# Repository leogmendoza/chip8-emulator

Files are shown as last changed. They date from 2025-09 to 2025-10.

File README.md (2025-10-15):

# 🍪 CHIP ATE
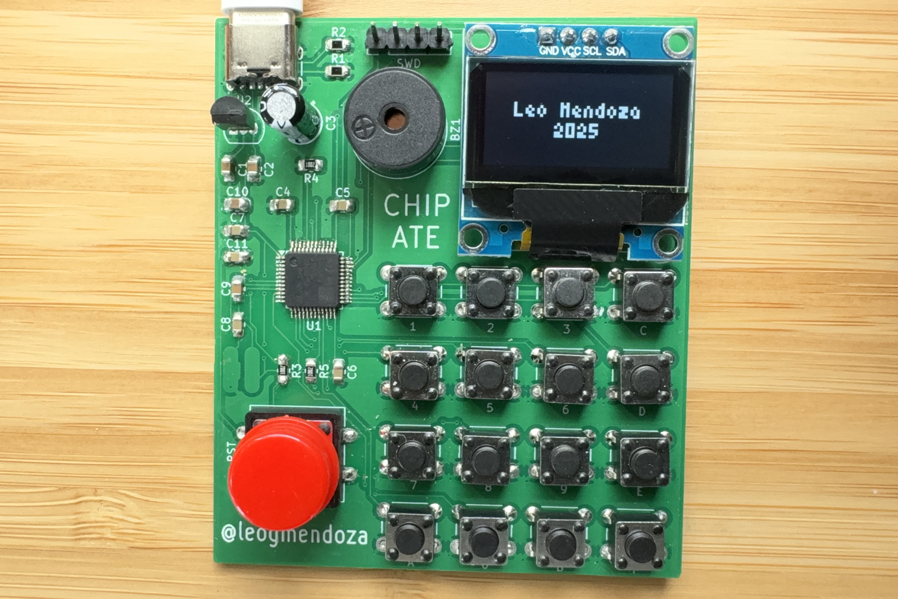
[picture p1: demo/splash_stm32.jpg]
 

## 🤔 What?
CHIP ATE is a CHIP-8 Emulator implemented on both PC using SDL2 and STM32 with a custom PCB!

## 🤨 Why?
This was supposed to be my first step into console emulation, but then it became that for PCB design as well!

## Features
- **Portable Emulator Core**:  
  Implements the timers, memory, and CPU as per the [official CHIP-8 spec](http://devernay.free.fr/hacks/chip8/C8TECH10.HTM), including all 34 instructions

- **Platform Abstraction Layer**:  
  Able to run on either PC or STM32 using a platform-agnostic API layer
  
- **Custom PCB**:  
  Assembled on a STM32-based board with an OLED screen, keypad, a buzzer, and power regulation
  
- **ROM Menu**:  
  Provides seamless loading in and out of the ROM catalog

## Diagrams

### System Architecture
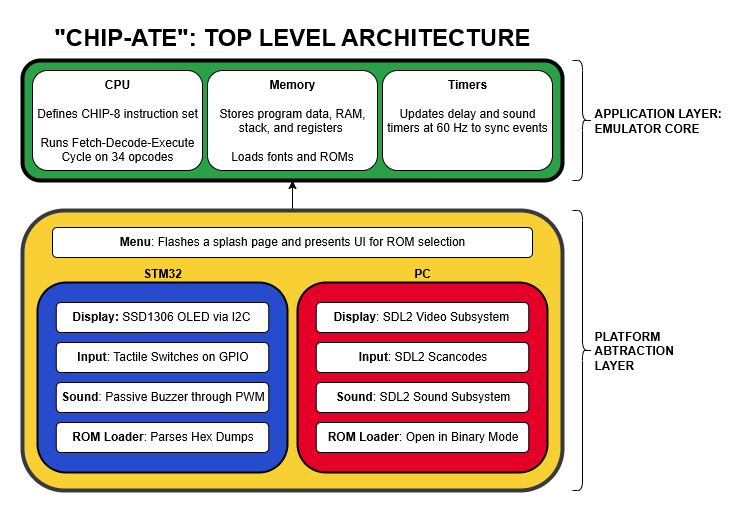
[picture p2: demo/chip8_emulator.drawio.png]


### Schematic
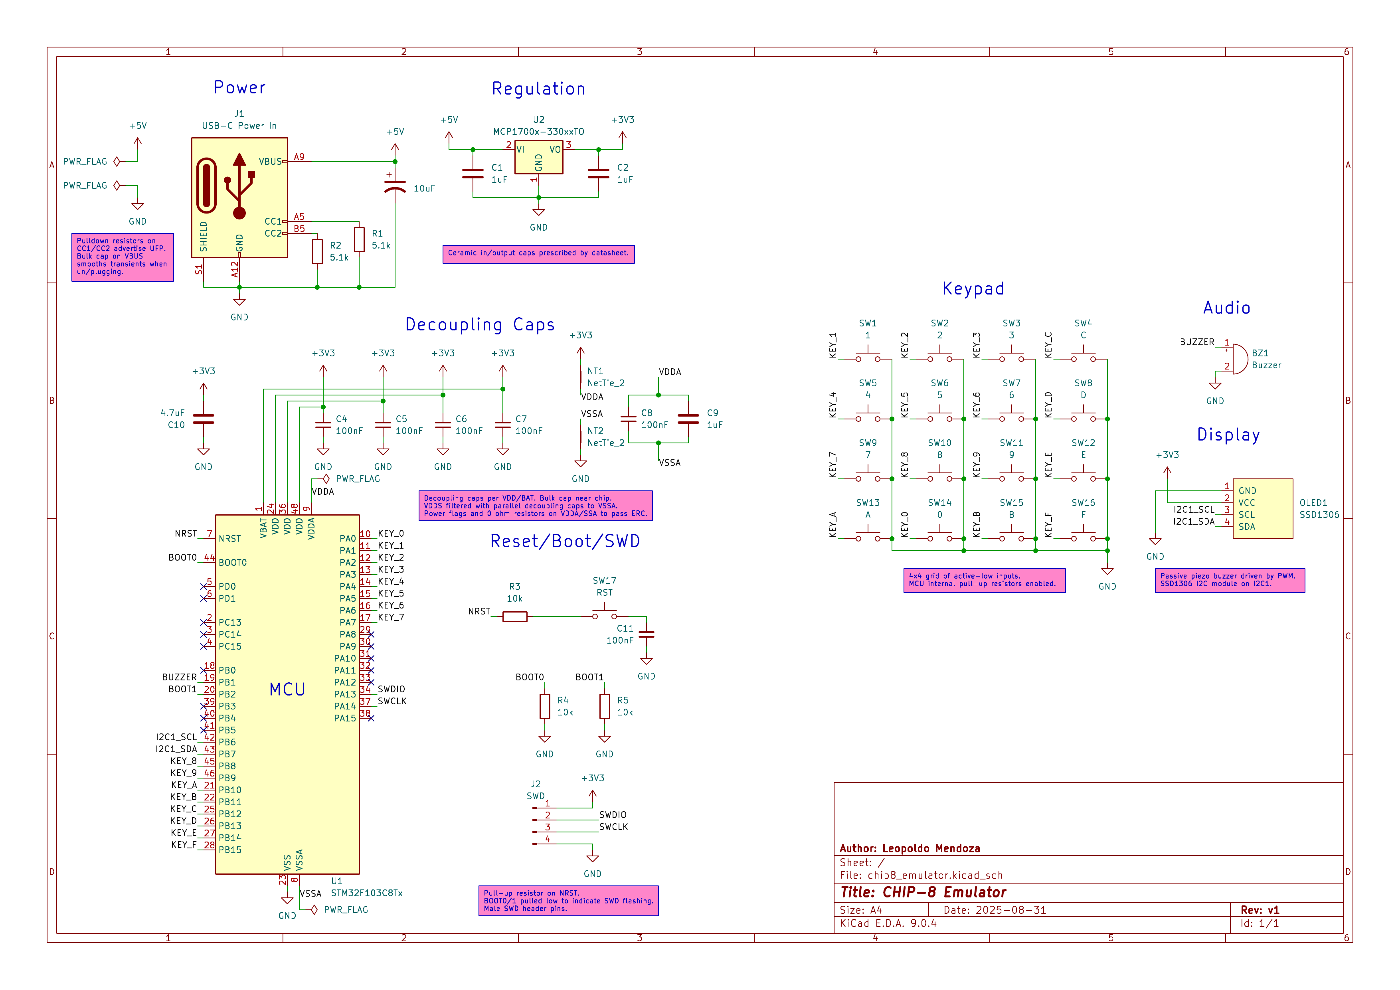
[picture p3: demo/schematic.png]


### Routing and 3D Renders
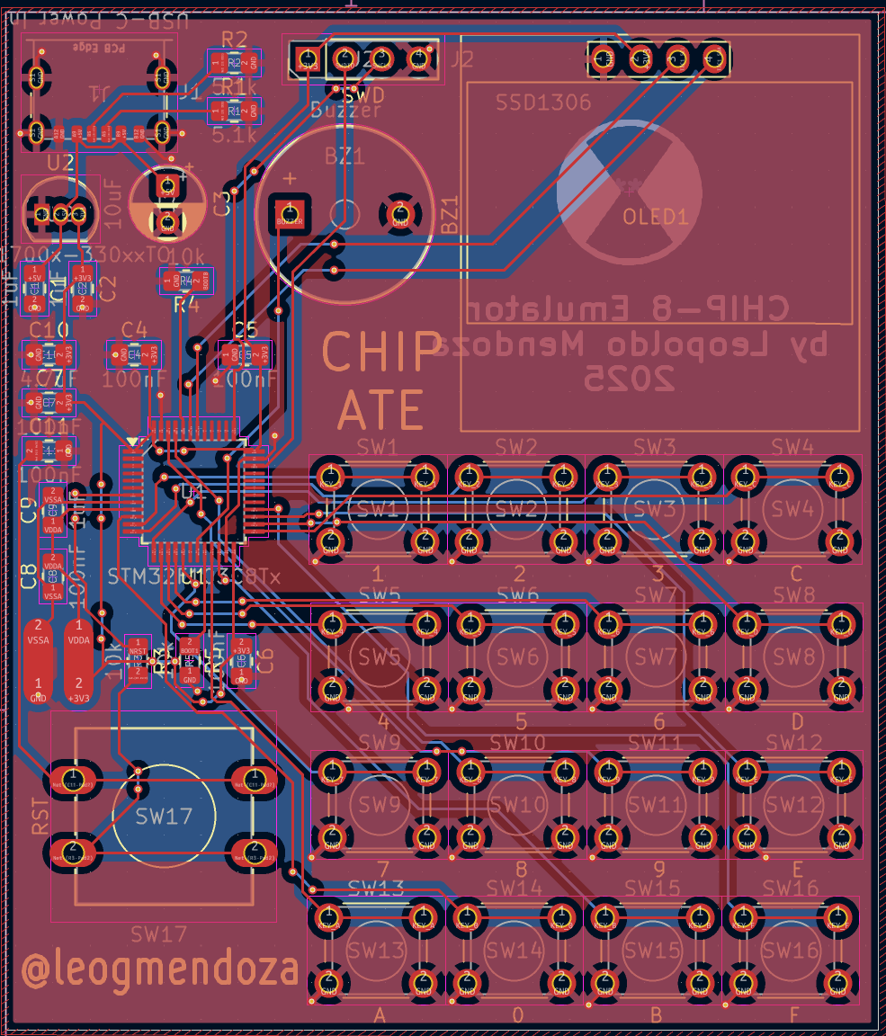
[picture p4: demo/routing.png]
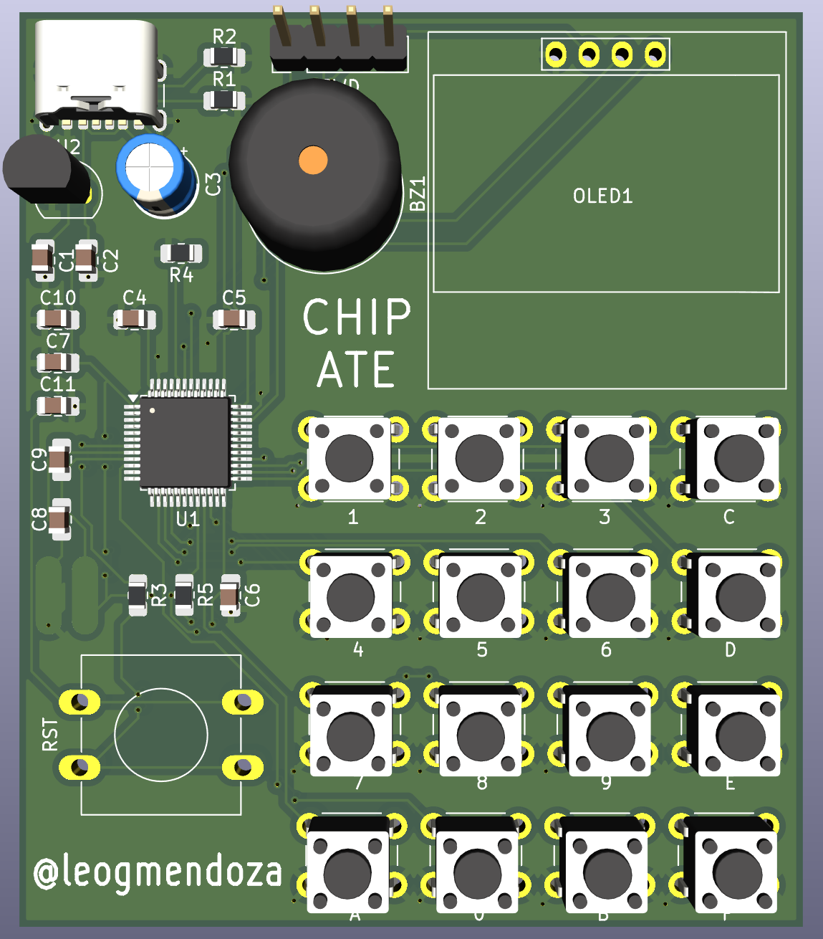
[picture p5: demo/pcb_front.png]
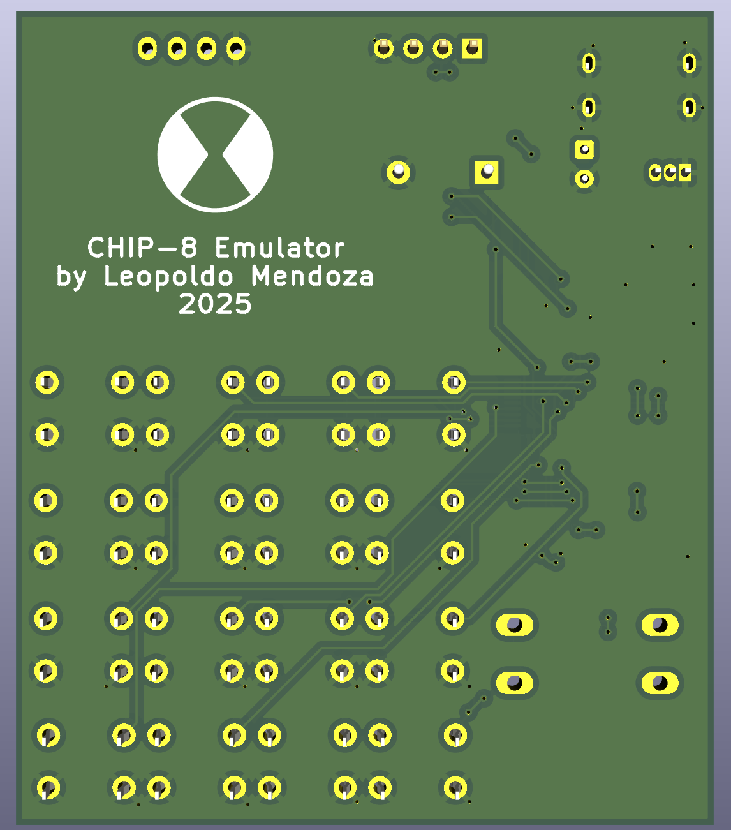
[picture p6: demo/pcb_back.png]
  

## 📸 STM32 Demos

### Demo Video (click it!)
<a href="https://youtu.be/Bx0_Uua0Y5I">
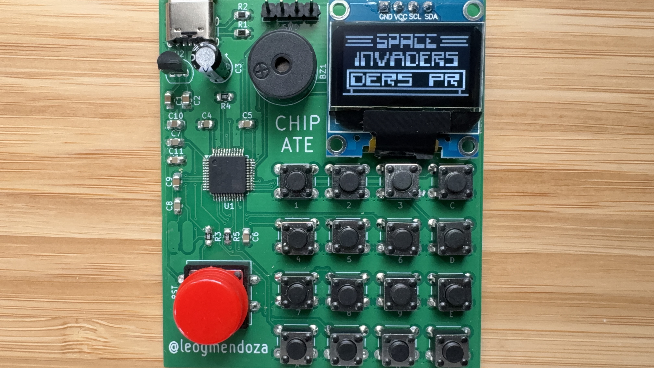
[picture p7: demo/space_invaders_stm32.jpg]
STM32 Demo
  
</a>

### Tetris
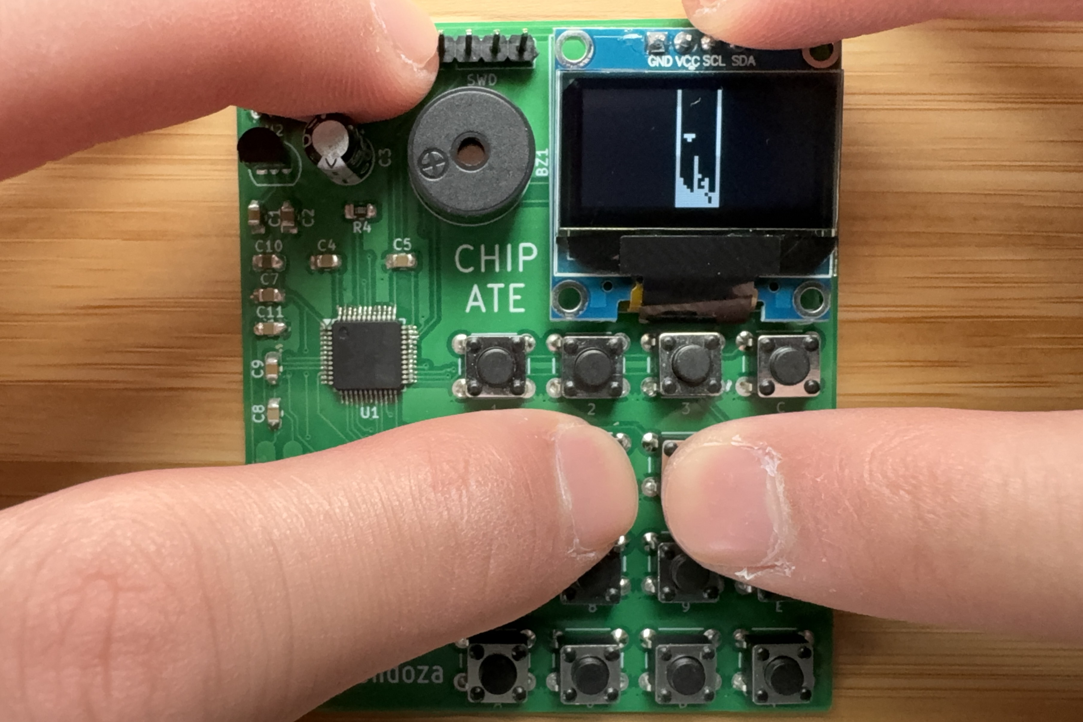
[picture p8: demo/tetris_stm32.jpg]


### Tic-Tac-Toe
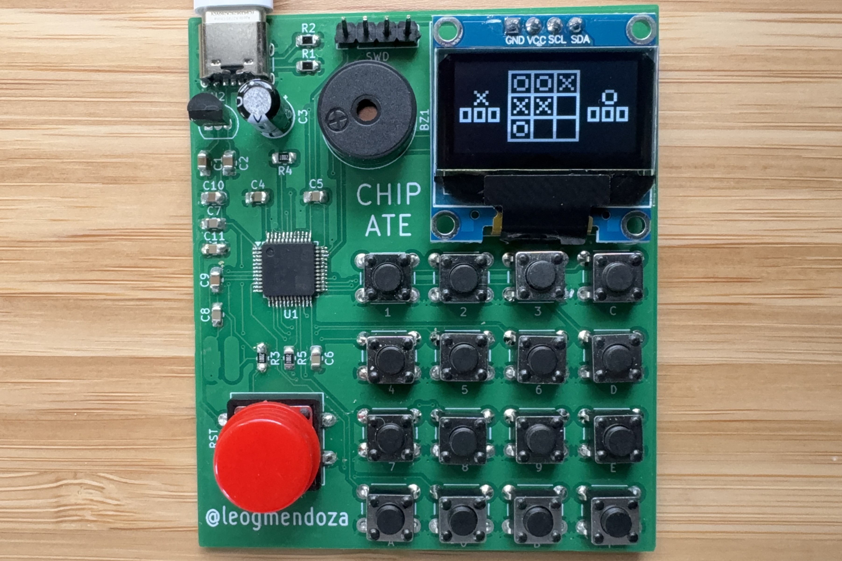
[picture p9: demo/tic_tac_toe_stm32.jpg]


### Pong
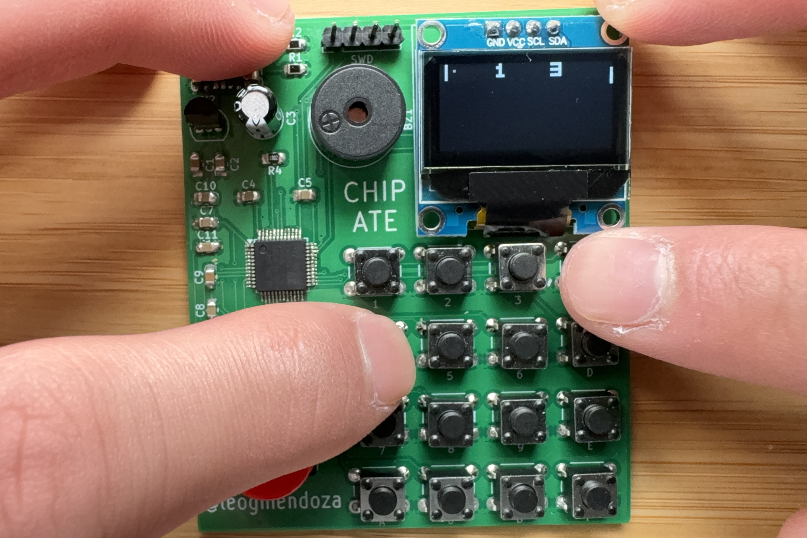
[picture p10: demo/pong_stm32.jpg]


## 📸 PC Demos

### Demo Video (click it!)
<a href="https://youtu.be/zPvpcgly5Rw">
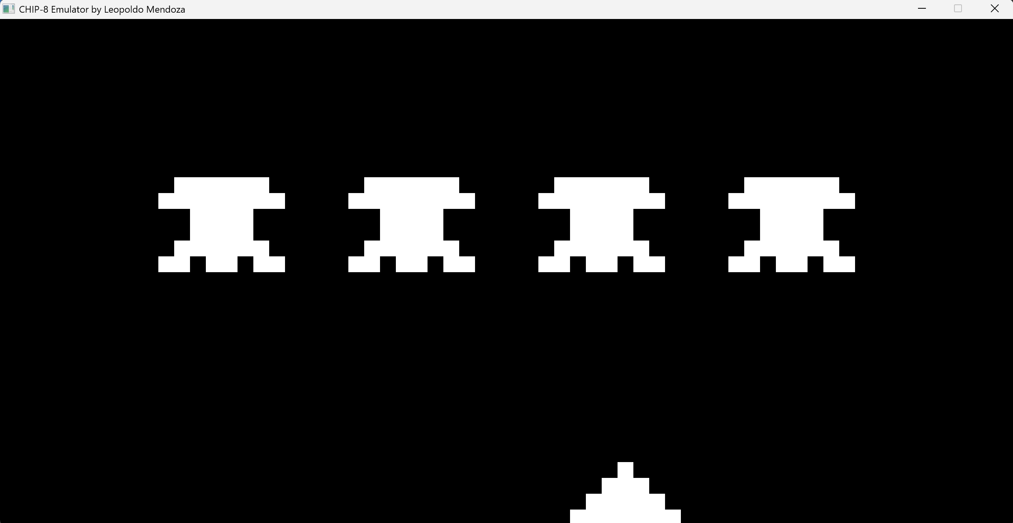
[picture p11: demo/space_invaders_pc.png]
PC Demo
  
</a>

### Startup Screen
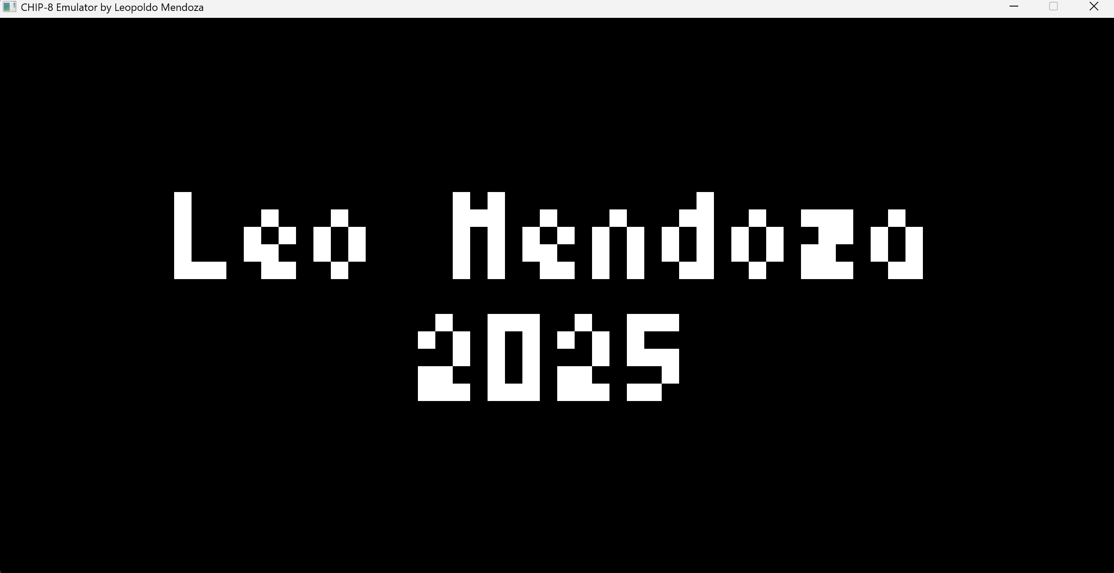
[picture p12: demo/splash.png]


### Menu
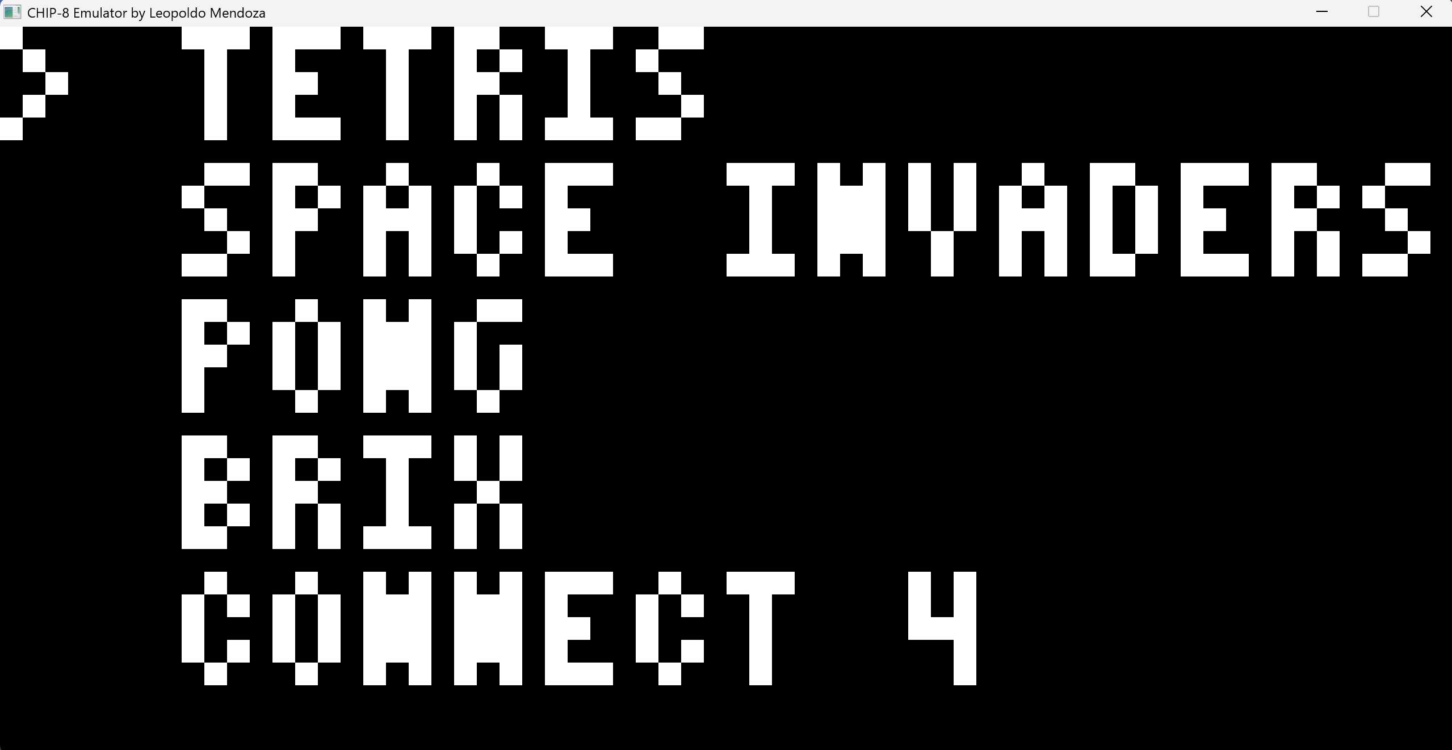
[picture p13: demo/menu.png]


### Opcode Test
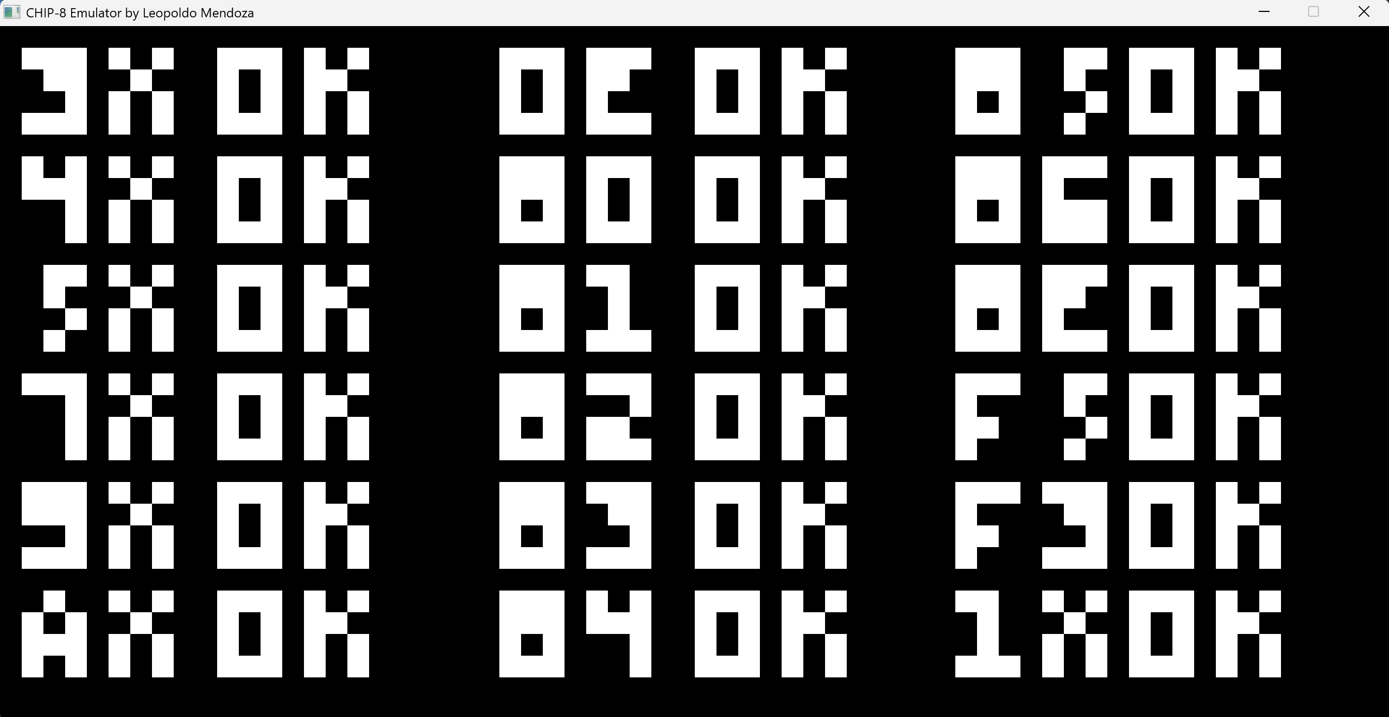
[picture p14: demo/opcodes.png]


## Resources
- [Guide to Making a CHIP-8 Emulator](https://tobiasvl.github.io/blog/write-a-chip-8-emulator/) by Tobias V. Langhoff
- [Building a CHIP-8 Emulator in C++](https://austinmorlan.com/posts/chip8_emulator/) by Austin Morlan
- [chip8stm32 Repo](https://github.com/AlfonsoJLuna/chip8stm32) by AlfonsoJLuna
- [KiCad Tutorial Playlist](https://youtube.com/playlist?list=PL3bNyZYHcRSUhUXUt51W6nKvxx2ORvUQB&si=zccgU5XXFSJnHfGM) by Shawn Hymel
- [KiCad 7 PCB Layout in 5 Steps](https://youtu.be/3FGNw28xBr0?si=mEvIMN-HYlVow5y7) by The Design Graveyard

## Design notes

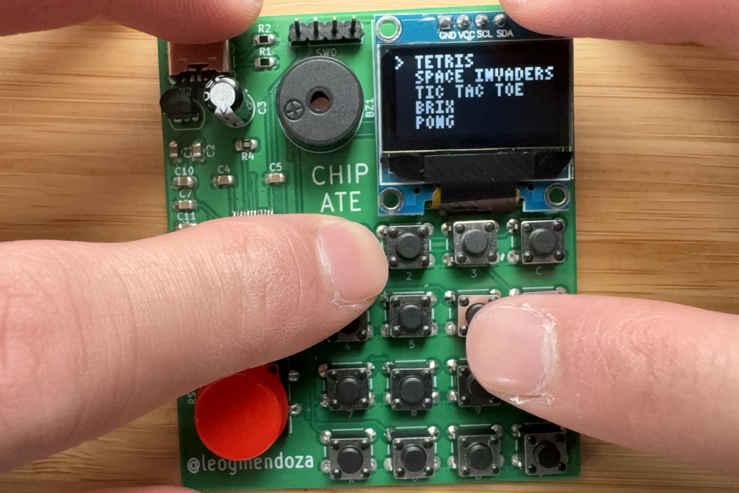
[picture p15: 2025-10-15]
demo/menu_stm32.jpg

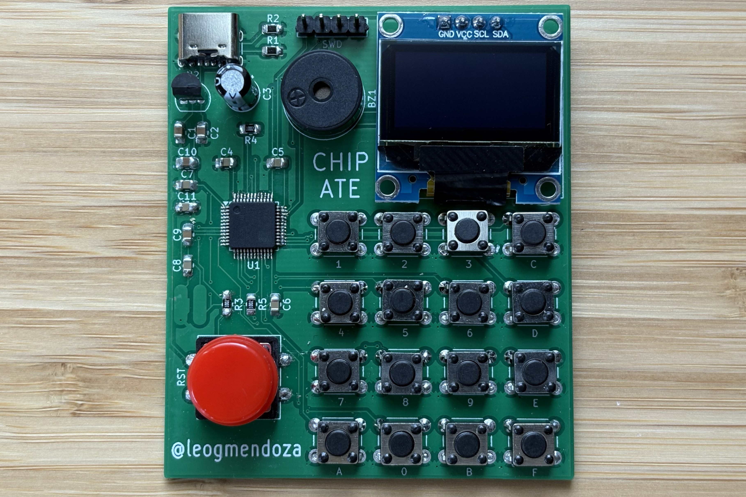
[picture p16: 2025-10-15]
demo/pcb_off.jpg

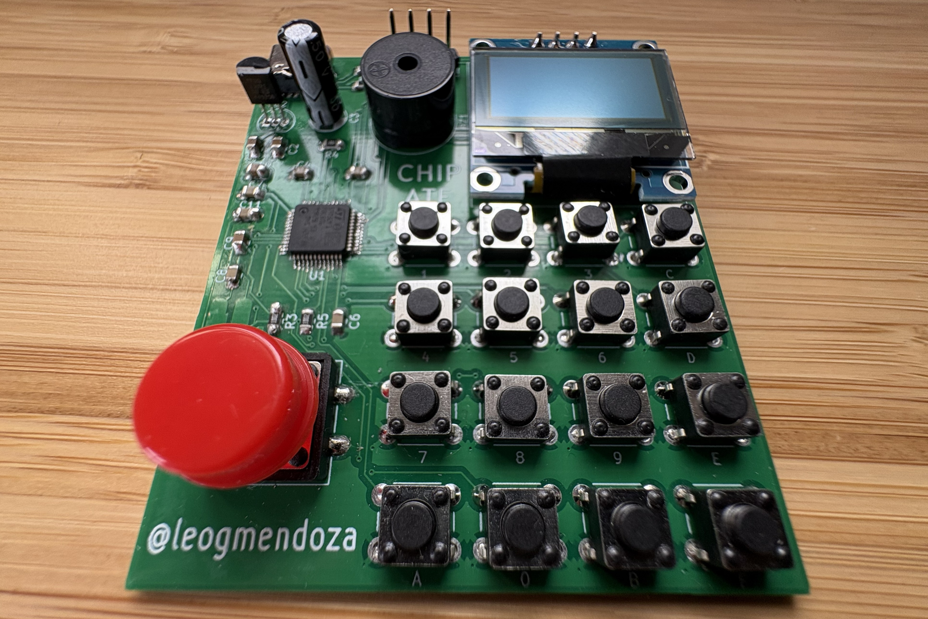
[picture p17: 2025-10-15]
demo/pcb_off_superman.jpg

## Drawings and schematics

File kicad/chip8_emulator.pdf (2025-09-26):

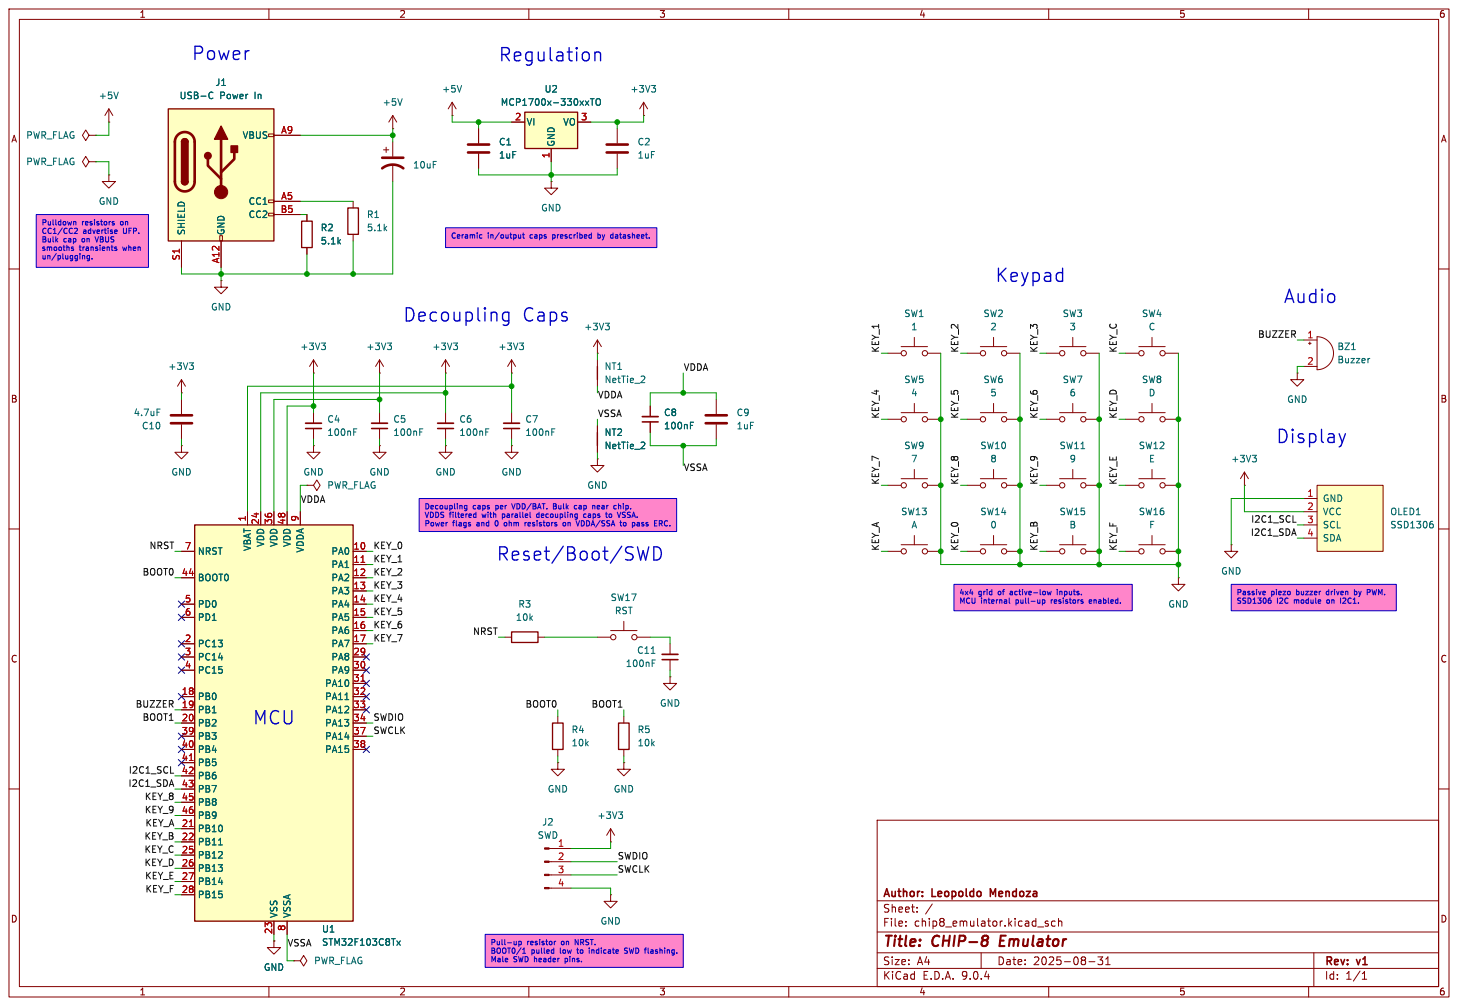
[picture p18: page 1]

1 VDD 24 VDD 36 VSS 23 VDD 48 VSSA

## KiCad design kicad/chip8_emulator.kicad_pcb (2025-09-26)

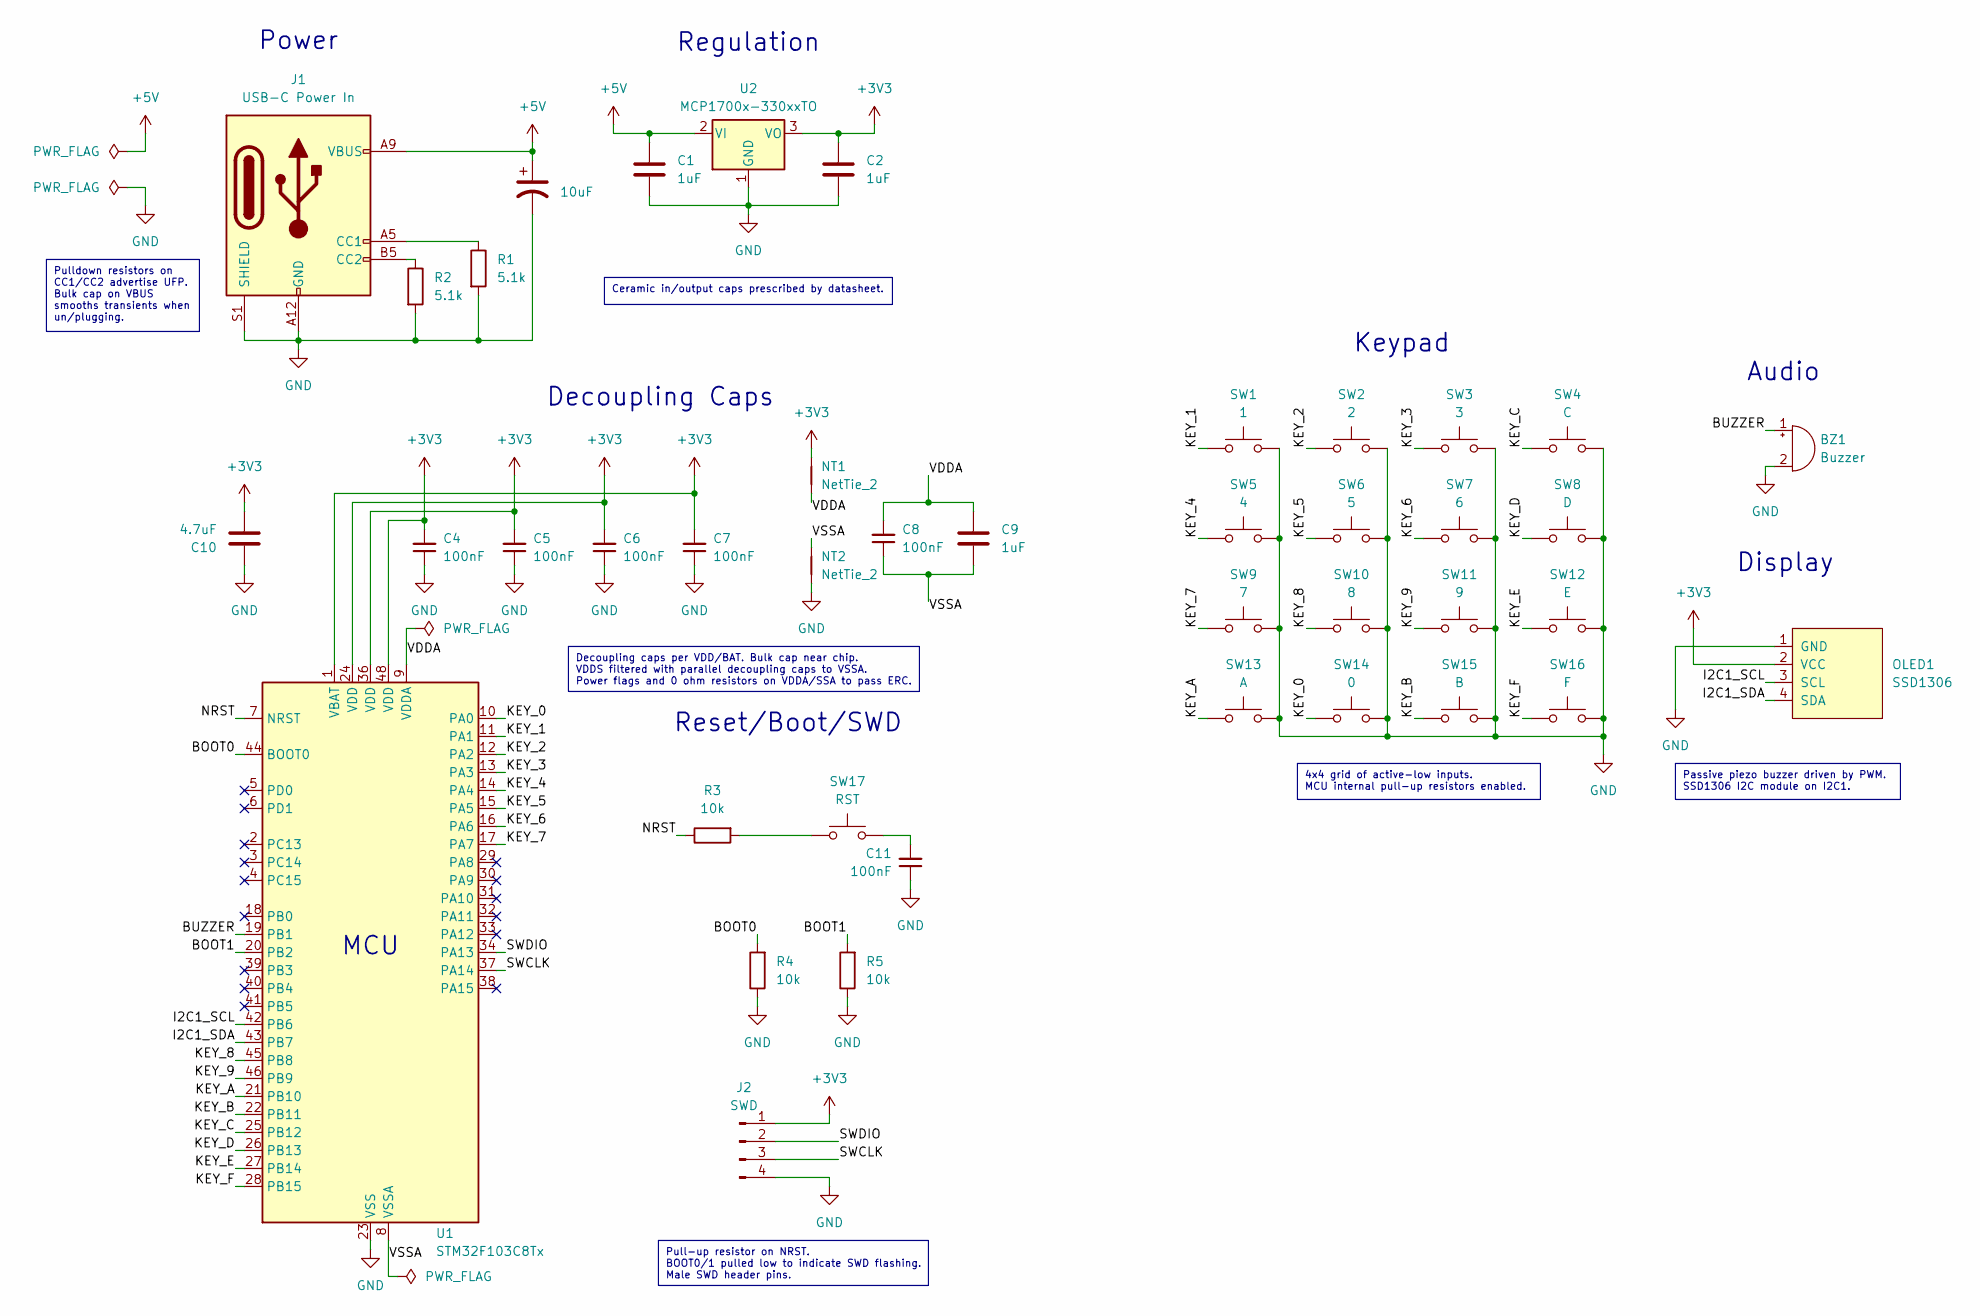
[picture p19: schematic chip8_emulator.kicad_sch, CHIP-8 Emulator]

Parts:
BZ1: Buzzer; Buzzer_12x9.5RM7.6
C1, C2, C9: 1uF; C_0805_2012Metric_Pad1.18x1.45mm_HandSolder
C3: 10uF; CP_Radial_D5.0mm_P2.50mm
C4, C5, C6, C7, C8, C11: 100nF; C_0805_2012Metric_Pad1.18x1.45mm_HandSolder
C10: 4.7uF; C_0805_2012Metric_Pad1.18x1.45mm_HandSolder
J1: USB-C Power In; USB_C_Receptacle_GCT_USB4125-xx-x_6P_TopMnt_Horizontal
J2: SWD; PinHeader_1x04_P2.54mm_Vertical
NT1, NT2: NetTie_2; NetTie-2_SMD_Pad2.0mm
OLED1: SSD1306; 128x64OLED
R1, R2: 5.1k; R_0805_2012Metric_Pad1.20x1.40mm_HandSolder
R3, R4, R5: 10k; R_0805_2012Metric_Pad1.20x1.40mm_HandSolder
SW1: 1; SW_PUSH_6mm_H4.3mm
SW2: 2; SW_PUSH_6mm_H4.3mm
SW3: 3; SW_PUSH_6mm_H4.3mm
SW4: C; SW_PUSH_6mm_H4.3mm
SW5: 4; SW_PUSH_6mm_H4.3mm
SW6: 5; SW_PUSH_6mm_H4.3mm
SW7: 6; SW_PUSH_6mm_H4.3mm
SW8: D; SW_PUSH_6mm_H4.3mm
SW9: 7; SW_PUSH_6mm_H4.3mm
SW10: 8; SW_PUSH_6mm_H4.3mm
SW11: 9; SW_PUSH_6mm_H4.3mm
SW12: E; SW_PUSH_6mm_H4.3mm
SW13: A; SW_PUSH_6mm_H4.3mm
SW14: 0; SW_PUSH_6mm_H4.3mm
SW15: B; SW_PUSH_6mm_H4.3mm
SW16: F; SW_PUSH_6mm_H4.3mm
SW17: RST; SW_PUSH-12mm
U1: STM32F103C8Tx; LQFP-48_7x7mm_P0.5mm
U2: MCP1700x-330xxTO; TO-92_Inline

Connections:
+3V3: C2.1, C4.2, C5.2, C6.2, C7.2, C10.2, J2.1, NT1.2, OLED1.2 (VCC), U1.1 (VBAT), U1.24 (VDD), U1.36 (VDD), U1.48 (VDD), U2.3 (VO)
+5V: C1.1, C3.1, J1.A9 (VBUS), J1.B9 (VBUS), U2.2 (VI)
/BOOT0: R4.2, U1.44 (BOOT0)
/BOOT1: R5.2, U1.20 (PB2)
/BUZZER: BZ1.1 (+), U1.19 (PB1)
/I2C1_SCL: OLED1.3 (SCL), U1.42 (PB6)
/I2C1_SDA: OLED1.4 (SDA), U1.43 (PB7)
/KEY_0: SW14.1, U1.10 (PA0)
/KEY_1: SW1.1, U1.11 (PA1)
/KEY_2: SW2.1, U1.12 (PA2)
/KEY_3: SW3.1, U1.13 (PA3)
/KEY_4: SW5.1, U1.14 (PA4)
/KEY_5: SW6.1, U1.15 (PA5)
/KEY_6: SW7.1, U1.16 (PA6)
/KEY_7: SW9.1, U1.17 (PA7)
/KEY_8: SW10.1, U1.45 (PB8)
/KEY_9: SW11.1, U1.46 (PB9)
/KEY_A: SW13.1, U1.21 (PB10)
/KEY_B: SW15.1, U1.22 (PB11)
/KEY_C: SW4.1, U1.25 (PB12)
/KEY_D: SW8.1, U1.26 (PB13)
/KEY_E: SW12.1, U1.27 (PB14)
/KEY_F: SW16.1, U1.28 (PB15)
/NRST: R3.1, U1.7 (NRST)
/SWCLK: J2.3, U1.37 (PA14)
/SWDIO: J2.2, U1.34 (PA13)
/VDDA: C8.2, C9.1, NT1.1, U1.9 (VDDA)
/VSSA: C8.1, C9.2, NT2.2, U1.8 (VSSA)
GND: BZ1.2 (-), C1.2, C2.2, C3.2, C4.1, C5.1, C6.1, C7.1, C10.1, C11.1, J1.A12 (GND), J1.B12 (GND), J1.S1 (SHIELD), J2.4, NT2.1, OLED1.1 (GND), R1.2, R2.2, R4.1, R5.1, SW1.2, SW2.2, SW3.2, SW4.2, SW5.2, SW6.2, SW7.2, SW8.2, SW9.2, SW10.2, SW11.2, SW12.2, SW13.2, SW14.2, SW15.2, SW16.2, U1.23 (VSS), U1.35 (VSS), U1.47 (VSS), U2.1 (GND)
unnamed: C11.2, SW17.1
unnamed: J1.A5 (CC1), R1.1
unnamed: J1.B5 (CC2), R2.1
unnamed: R3.2, SW17.2

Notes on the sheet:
Regulation
Decoupling Caps
Display
Power
Audio
MCU
Keypad
Reset/Boot/SWD
Decoupling caps per VDD/BAT. Bulk cap near chip. VDDS filtered with parallel decoupling caps to VSSA. Power flags and 0 ohm resistors on VDDA/SSA to pass ERC.
Ceramic in/output caps prescribed by datasheet.
Pulldown resistors on CC1/CC2 advertise UFP. Bulk cap on VBUS smooths transients when un/plugging.
Passive piezo buzzer driven by PWM. SSD1306 I2C module on I2C1.
Pull-up resistor on NRST. BOOT0/1 pulled low to indicate SWD flashing. Male SWD header pins.
4x4 grid of active-low inputs. MCU internal pull-up resistors enabled.

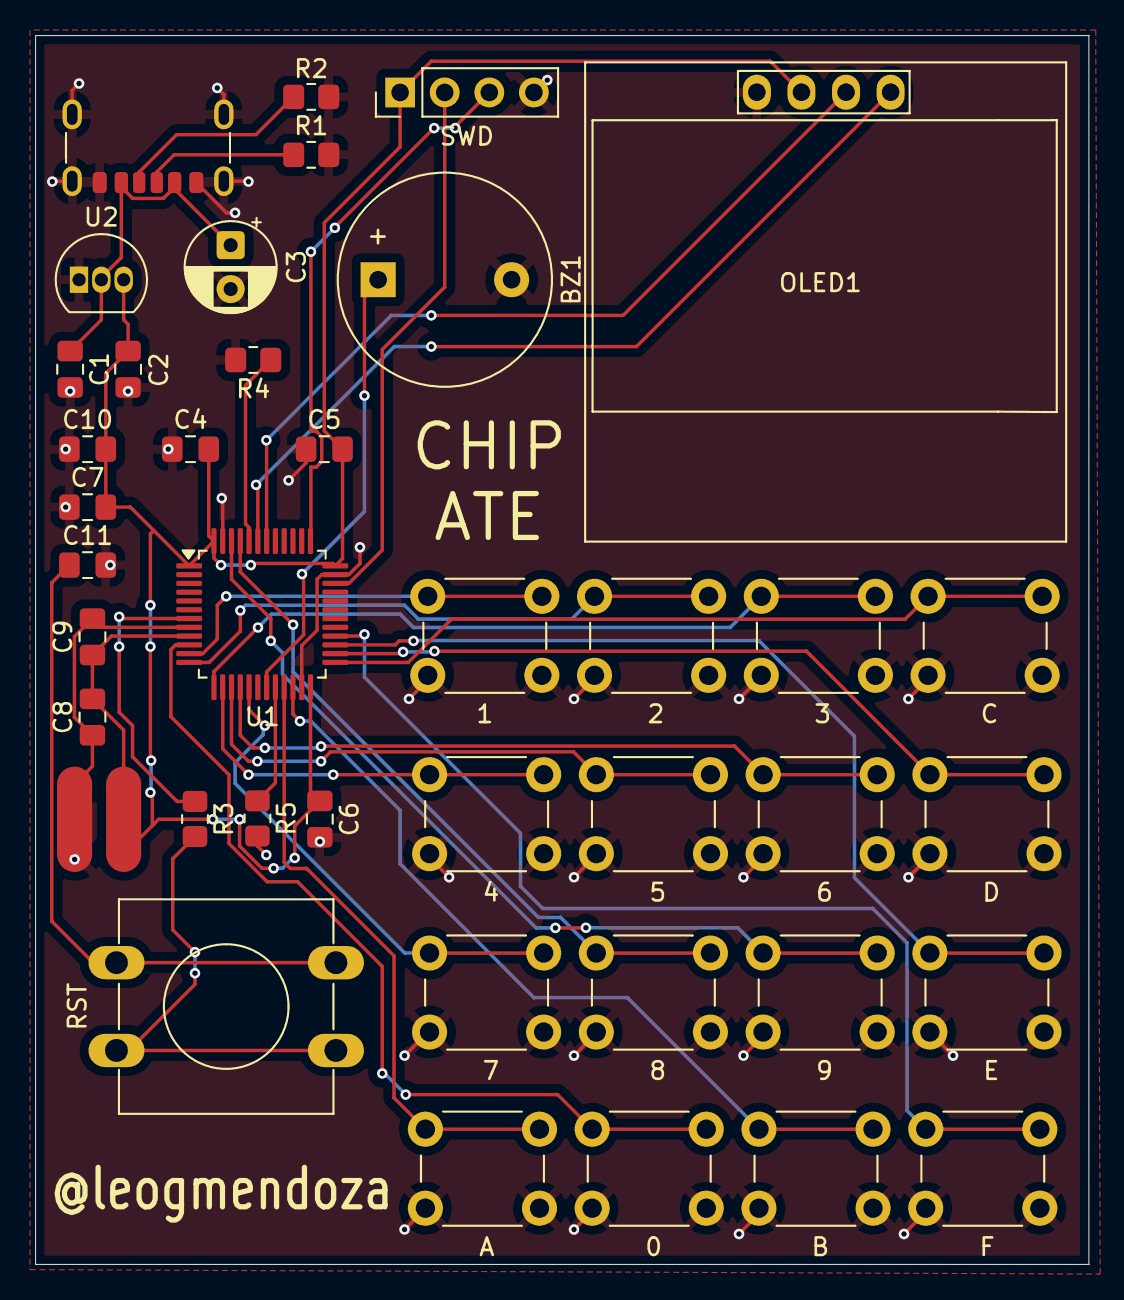
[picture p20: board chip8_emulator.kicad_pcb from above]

Board: 2 copper layers, 60.0 x 70.0 mm, 41 parts (0 on the bottom side), 33 nets.

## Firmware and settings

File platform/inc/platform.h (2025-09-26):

#pragma once

// Config params
#define DISPLAY_SCALE 20
// Overriden at runtime (right now, 8 works best for PC implementation on Tetris and Space Invaders)
#define DEFAULT_INSTRUCTIONS_PER_FRAME 10
#define DEFAULT_CPU_CYCLE_DELAY_MS 3  // Try to keep at 0 for STM32 since MCU won't benefit from delays

/* Uncomment depending on the platform */
#define PLATFORM_PC
// #define PLATFORM_STM32

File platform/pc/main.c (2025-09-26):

#include <stdio.h>

#include "chip8.h"
#include "platform.h"
#include "cpu.h"
#include "rom.h"
#include "display.h"
#include "input.h"
#include "timers.h"
#include "timing.h"
#include "sound.h"
#include "menu.h"

#ifdef PLATFORM_PC

int main(int argc, char *argv[]) {
    printf("Booting up the Chip-8 Emulator!\n");

    int instructions_per_frame = DEFAULT_INSTRUCTIONS_PER_FRAME;
    int cpu_cycle_delay_ms = DEFAULT_CPU_CYCLE_DELAY_MS;

    Chip8 chip8;
    chip8_init(&chip8);

    // Set up platform subsystems
    if (platform_display_init(DISPLAY_SCALE) != 0) {
        printf("Display could not be initialized");

        return 1;
    }

    if (platform_input_init() != 0) {
        printf("Input could not be initialized");

        return 1;
    }

    if (platform_timing_init(cpu_cycle_delay_ms) != 0) {
        printf("Timing could not be initialized");

        return 1;
    }

    if (platform_sound_init() != 0) {
        printf("Sound could not be initialized");

        return 1;
    }

    int running = 1;

    // ROM path specified (CLI override)
    if (argc > 1) {
        rom_load_rom(&chip8, argv[1]);
    // Pre-ROM loop
    } else {
        platform_menu_init();

        while (running) {
            // Handle window closing gracefully during startup
            running = platform_display_poll_events();

            if (!running) {
                break;
            }

            // Update keypad and feed to the menu
            platform_input_update(chip8.keypad);

            if (platform_menu_update(&chip8, chip8.keypad) == MENU_IDLE) {
                break;
            }


            // Draw the menu and keep audio silent
            platform_menu_draw();

            // Maintain frame pacing (same clock as the emulator)
            platform_timing_sync(&chip8);
        }

        if (!running) {
            // User closed the window from the menu
            platform_sound_destroy();
            platform_display_destroy();
            platform_input_destroy();
            platform_timing_destroy();

            return 0;
        }
    }

    while(running) {
        // Handle window closing gracefully
        running = platform_display_poll_events();

        // Poll for pressed inputs
        platform_input_update(chip8.keypad);

        // Run multiple instructions per frame
        for (size_t i = 0; i < instructions_per_frame; ++i) {
            cpu_cycle(&chip8);
        }

        // Draw once per frame
        platform_display_draw(chip8.display);

        // Beep while sound timer is activated
        platform_sound_update(chip8.sound_timer > 0);

        // Ensure ticking at desired FPS
        platform_timing_sync(&chip8);
    }
    
    platform_sound_destroy();  // Before SDL_Quit in display_destroy
    platform_display_destroy();
    platform_input_destroy();
    platform_timing_destroy();

    return 0;
}

#endif

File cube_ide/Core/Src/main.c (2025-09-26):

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
/* Includes ------------------------------------------------------------------*/
#include "main.h"

/* USER CODE BEGIN Includes */
#include "chip8.h"
#include "app.h"
/* USER CODE END Includes */

I2C_HandleTypeDef hi2c1;

TIM_HandleTypeDef htim3;

void SystemClock_Config(void);
static void MX_GPIO_Init(void);
static void MX_I2C1_Init(void);
static void MX_TIM3_Init(void);
/**
  * @brief  The application entry point.
  * @retval int
  */
int main(void)
{

  /* MCU Configuration--------------------------------------------------------*/

  /* Reset of all peripherals, Initializes the Flash interface and the Systick. */
  HAL_Init();

  /* Configure the system clock */
  SystemClock_Config();

  /* Initialize all configured peripherals */
  MX_GPIO_Init();
  MX_I2C1_Init();
  MX_TIM3_Init();
  /* USER CODE BEGIN 2 */

  app();

  /* USER CODE END 2 */

  /* Infinite loop */
  /* USER CODE BEGIN WHILE */
  while (1)
  {
    /* USER CODE END WHILE */

    /* USER CODE BEGIN 3 */
  }
  /* USER CODE END 3 */
}

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


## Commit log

2025-08-23 Resolve Cmake issues and prep main
    [main.c, platform.h]
2025-08-24 Implement instruction skip operations
    [display.c]
2025-08-25 Fix minor bugs with drawing and mem safety
    [display.c]
2025-08-29 tested display, uncommented erthing else, did not work due to unsoldered board
    [display.c, main.c, platform.h]
2025-08-29 Soldered MCU header pins and implemented input >:D
2025-09-26 Add STM32CubeIDE files
2025-09-26 Add KiCad files
    [chip8_emulator.kicad_pcb, chip8_emulator.kicad_sch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]

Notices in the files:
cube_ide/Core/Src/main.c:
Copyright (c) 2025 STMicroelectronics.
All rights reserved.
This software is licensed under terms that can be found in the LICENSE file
